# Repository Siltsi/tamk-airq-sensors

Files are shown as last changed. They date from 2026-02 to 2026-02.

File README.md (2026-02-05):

# TAMK AIRQ SENSORS  

## TEAM25  

**Members**  
- Eino Lausmaa ([@eino](https://github.com/LausmaaEino))  
- Samu Ojala ([@samu](https://github.com/SamuOj))  
- Tomi Tienhaara ([@tomi](https://github.com/TomiTien))  
- Totti Sillanpää ([@totti](https://github.com/Siltsi))  

## About  

This repository contains a hardware project developed for the **TAMK Summer Training 2025**. The project goal is to design and manifacture a custom circuit board and enclosure for **PCB-based particle sensor systems**.  

All PCBs in this project were designed using **KiCad**.  

## Models  

### ttgo_airq  

The **ttgo_airq** model is based on the LILYGO [T-Display](https://lilygo.cc/products/t-display). This model is currently in a **usable and tested state**.  

**Features:**  
- ESP32 with integrated display  
- Custom-designed PCB  
- 2 enclosure options  

**Enclosures:**  
- **Medium enclosure**  
  - Supports Sensirion [SEN5x](https://sensirion.com/products/catalog/SEK-SEN5x)  
  - Supports Sensirion [SCD41](https://sensirion.com/products/catalog/SEK-SCD41)  
- **Small enclosure**  
  - Supports Sensirion [SCD41](https://sensirion.com/products/catalog/SEK-SCD41) only  

### nodemcu_airq  

The **nodemcu_airq** model is based on the Joy-IT [NodeMCU ESP32](https://joy-it.net/en/products/SBC-NodeMCU-ESP32).  
This model is **still a work in progress**.  

**Current status:**  
- PCB design is expected to be functional  
- System-level development is ongoing  

**Display options:**  
- Large display using the Velleman [VMP400](https://www.velleman.eu/products/view/3-5-320-x-480-touchscreen-for-raspberry-pi-vmp400/?id=438240)  
- Smaller display  
- No display  

**Enclosures:**  
- No enclosures have been designed yet for this model

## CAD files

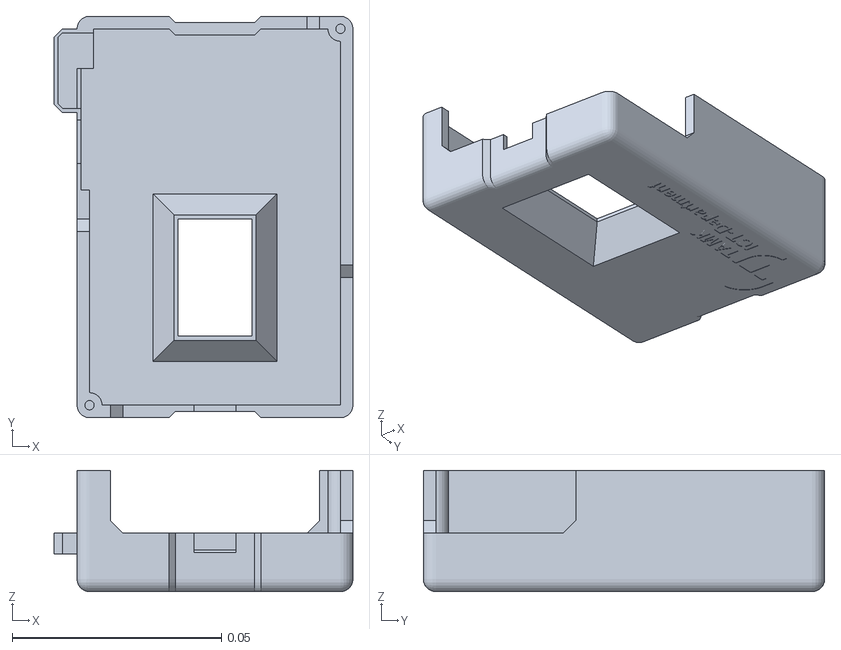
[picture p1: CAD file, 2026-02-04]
cases/ttgo_airq/small_case_top.stl
0.0715 x 0.096 x 0.029

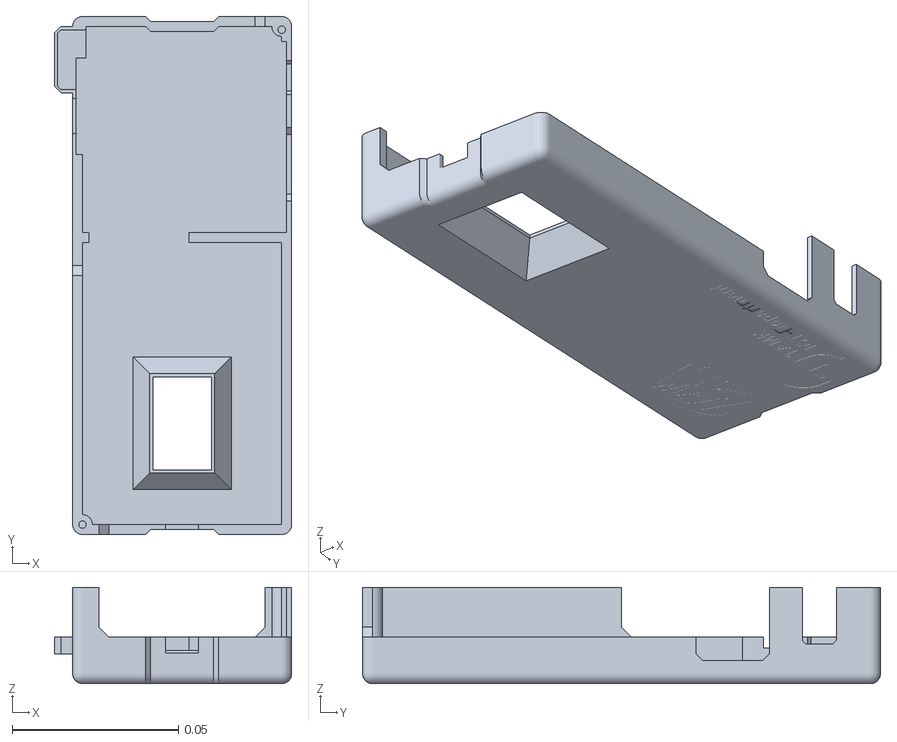
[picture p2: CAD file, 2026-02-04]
cases/ttgo_airq/medium_case_top_logo.stl
0.0715 x 0.156 x 0.029

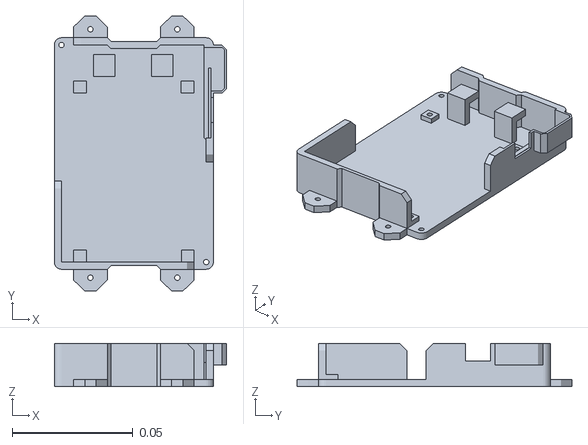
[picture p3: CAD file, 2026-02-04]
cases/ttgo_airq/small_case_bottom.stl
0.0715 x 0.114 x 0.018

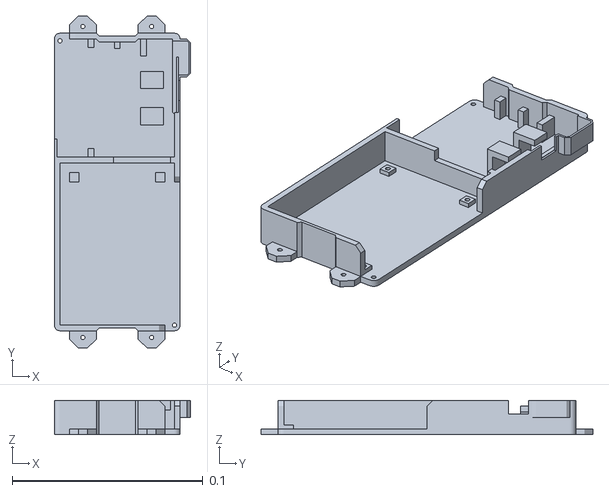
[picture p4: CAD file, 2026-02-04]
cases/ttgo_airq/medium_case_bottom.stl
0.0715 x 0.174 x 0.018

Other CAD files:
cases/ttgo_airq/medium_case_top.stl

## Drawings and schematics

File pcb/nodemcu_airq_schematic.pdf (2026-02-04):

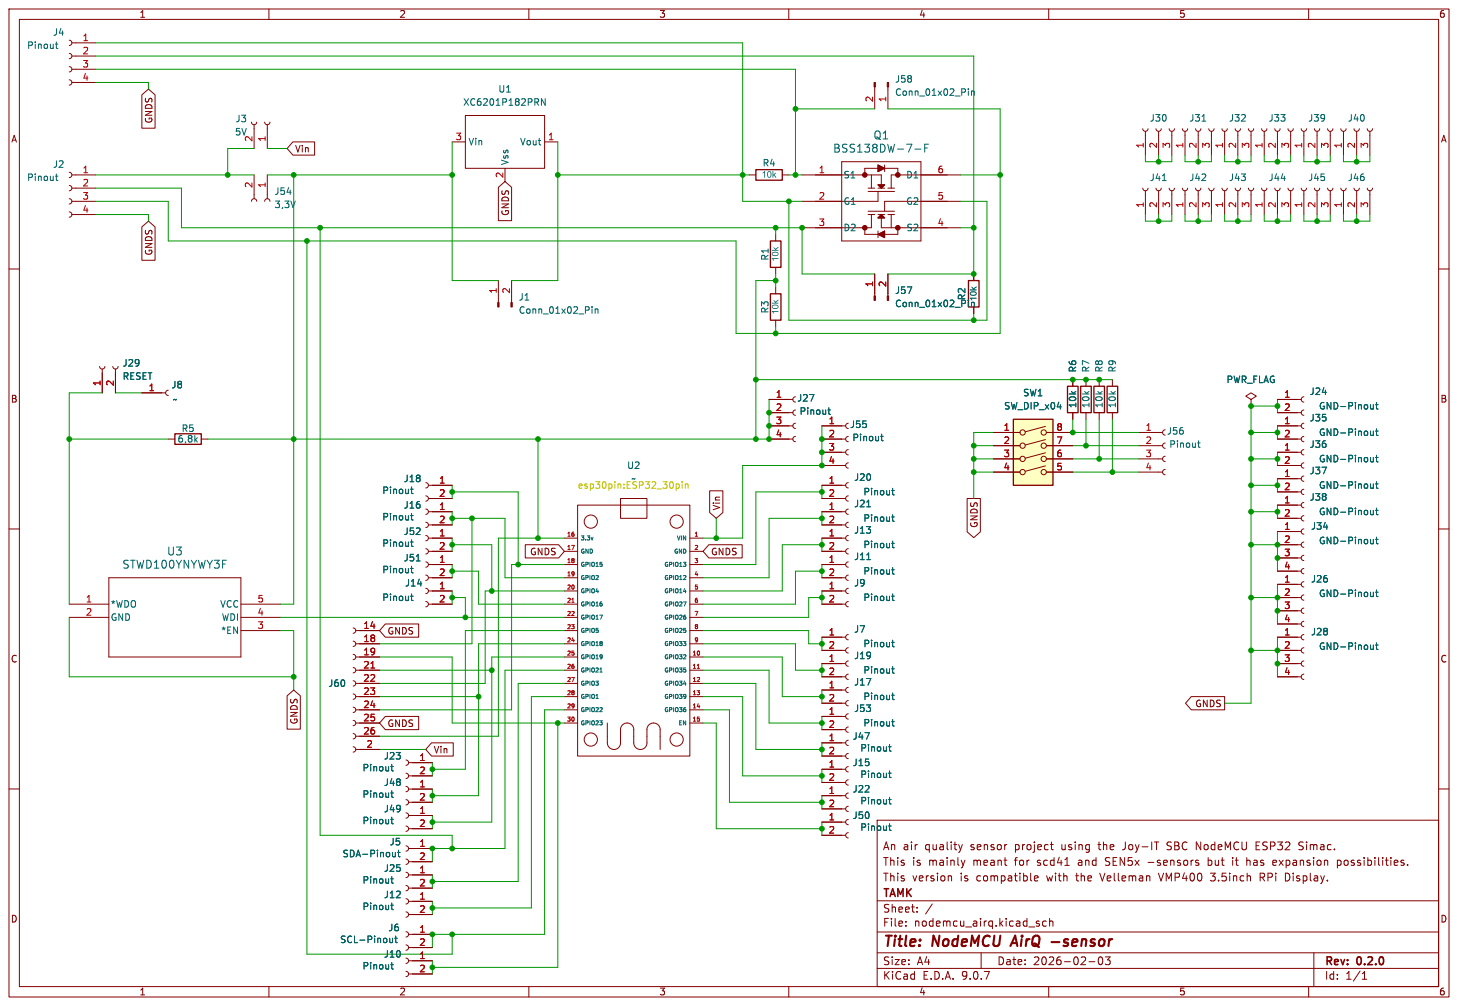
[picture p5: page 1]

Id: 1/1 Title: NodeMCU AirQ -sensor File: nodemcu_airq.kicad_sch Sheet: / TAMK

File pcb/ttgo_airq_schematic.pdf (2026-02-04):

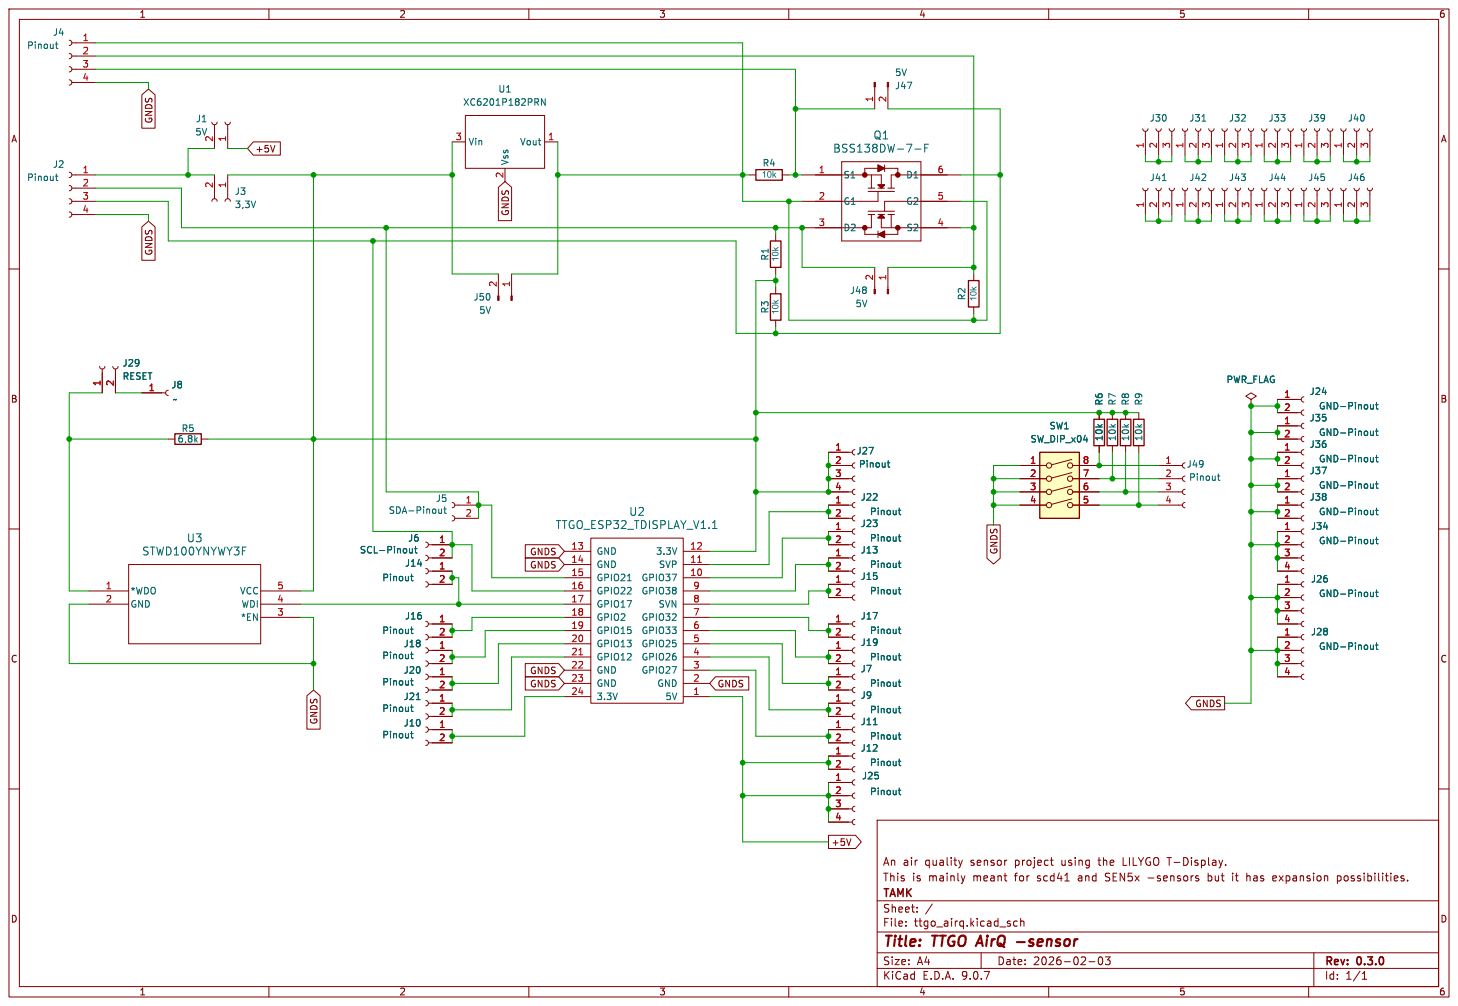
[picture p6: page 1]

Id: 1/1 Title: TTGO AirQ -sensor File: ttgo_airq.kicad_sch Sheet: / TAMK

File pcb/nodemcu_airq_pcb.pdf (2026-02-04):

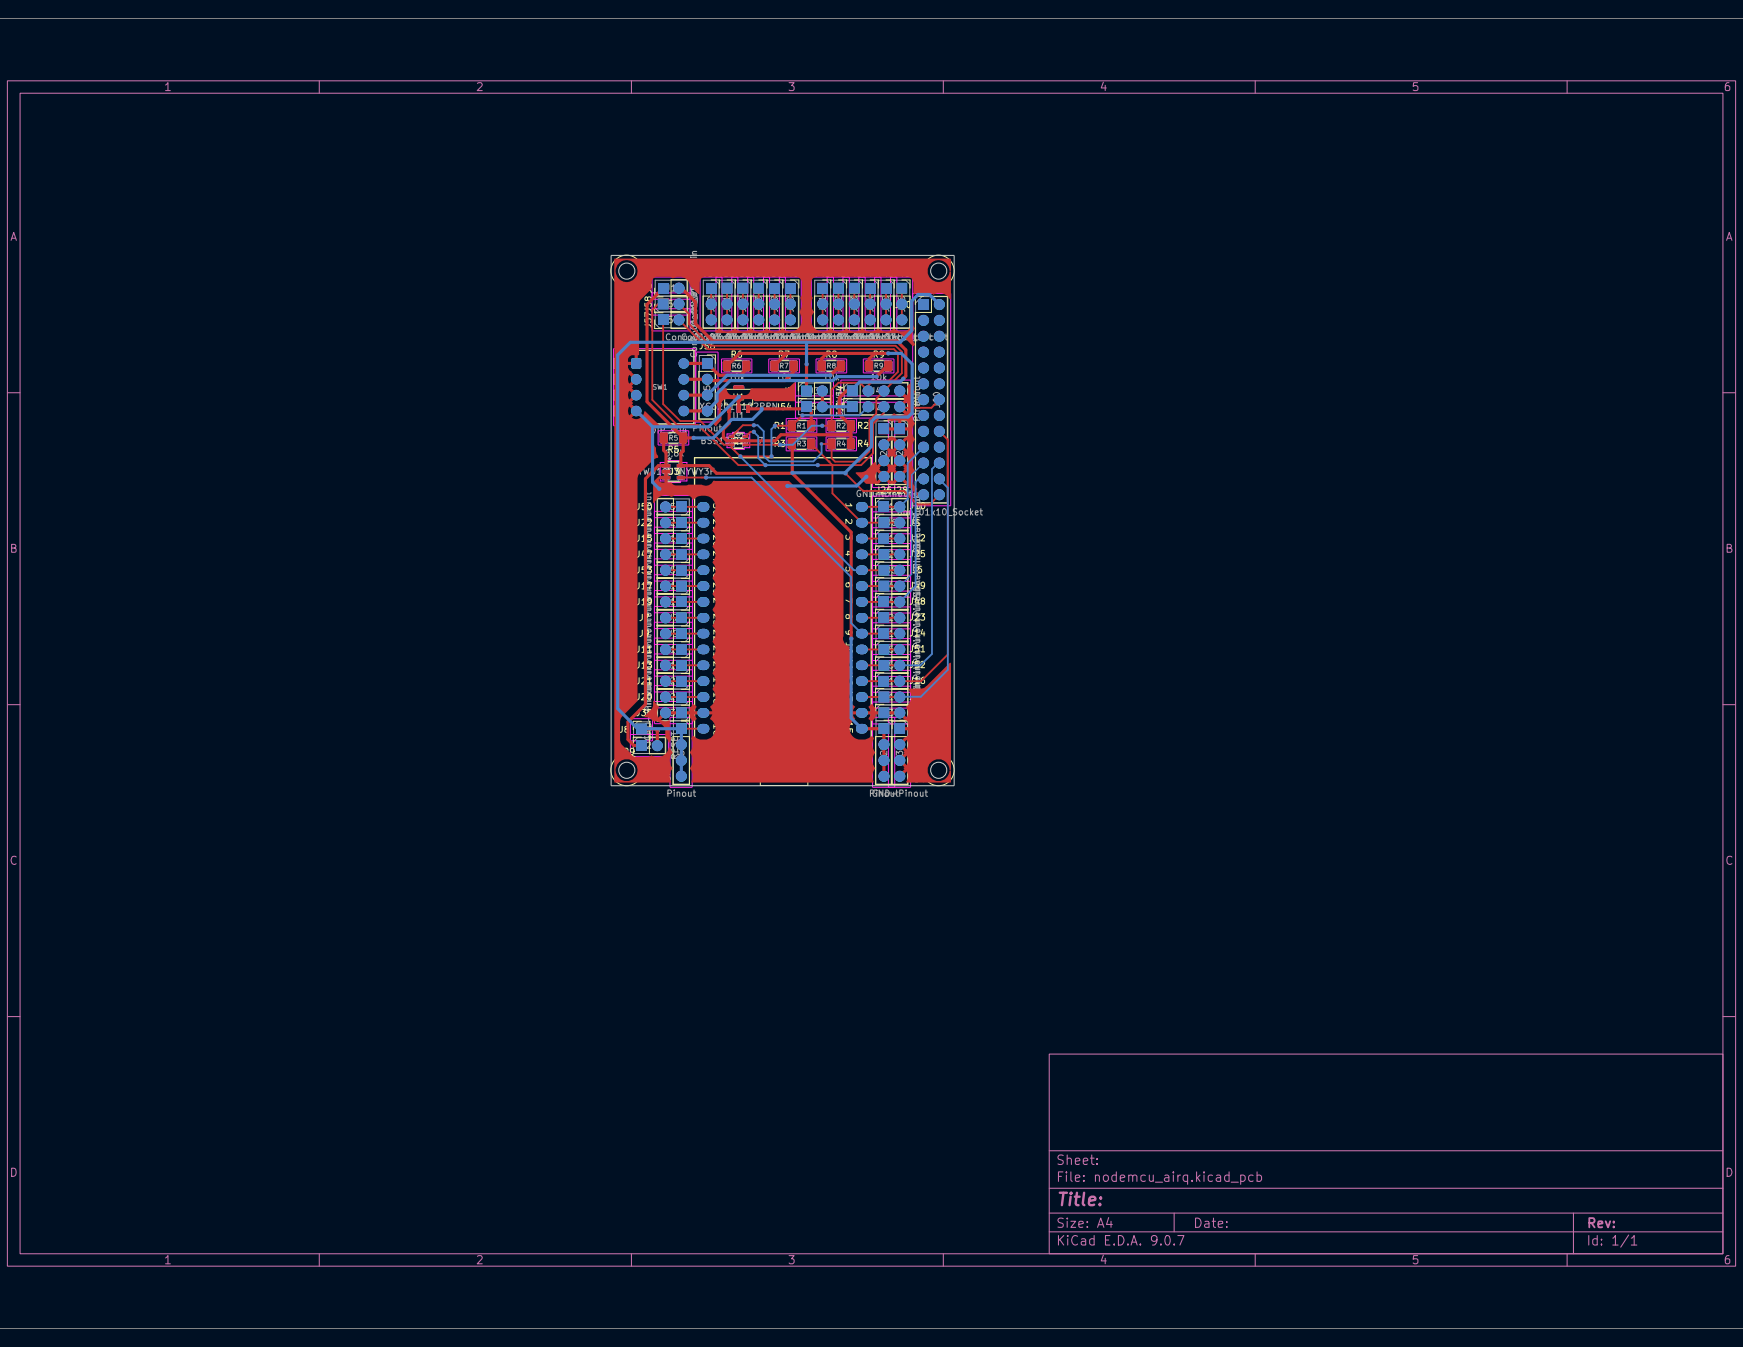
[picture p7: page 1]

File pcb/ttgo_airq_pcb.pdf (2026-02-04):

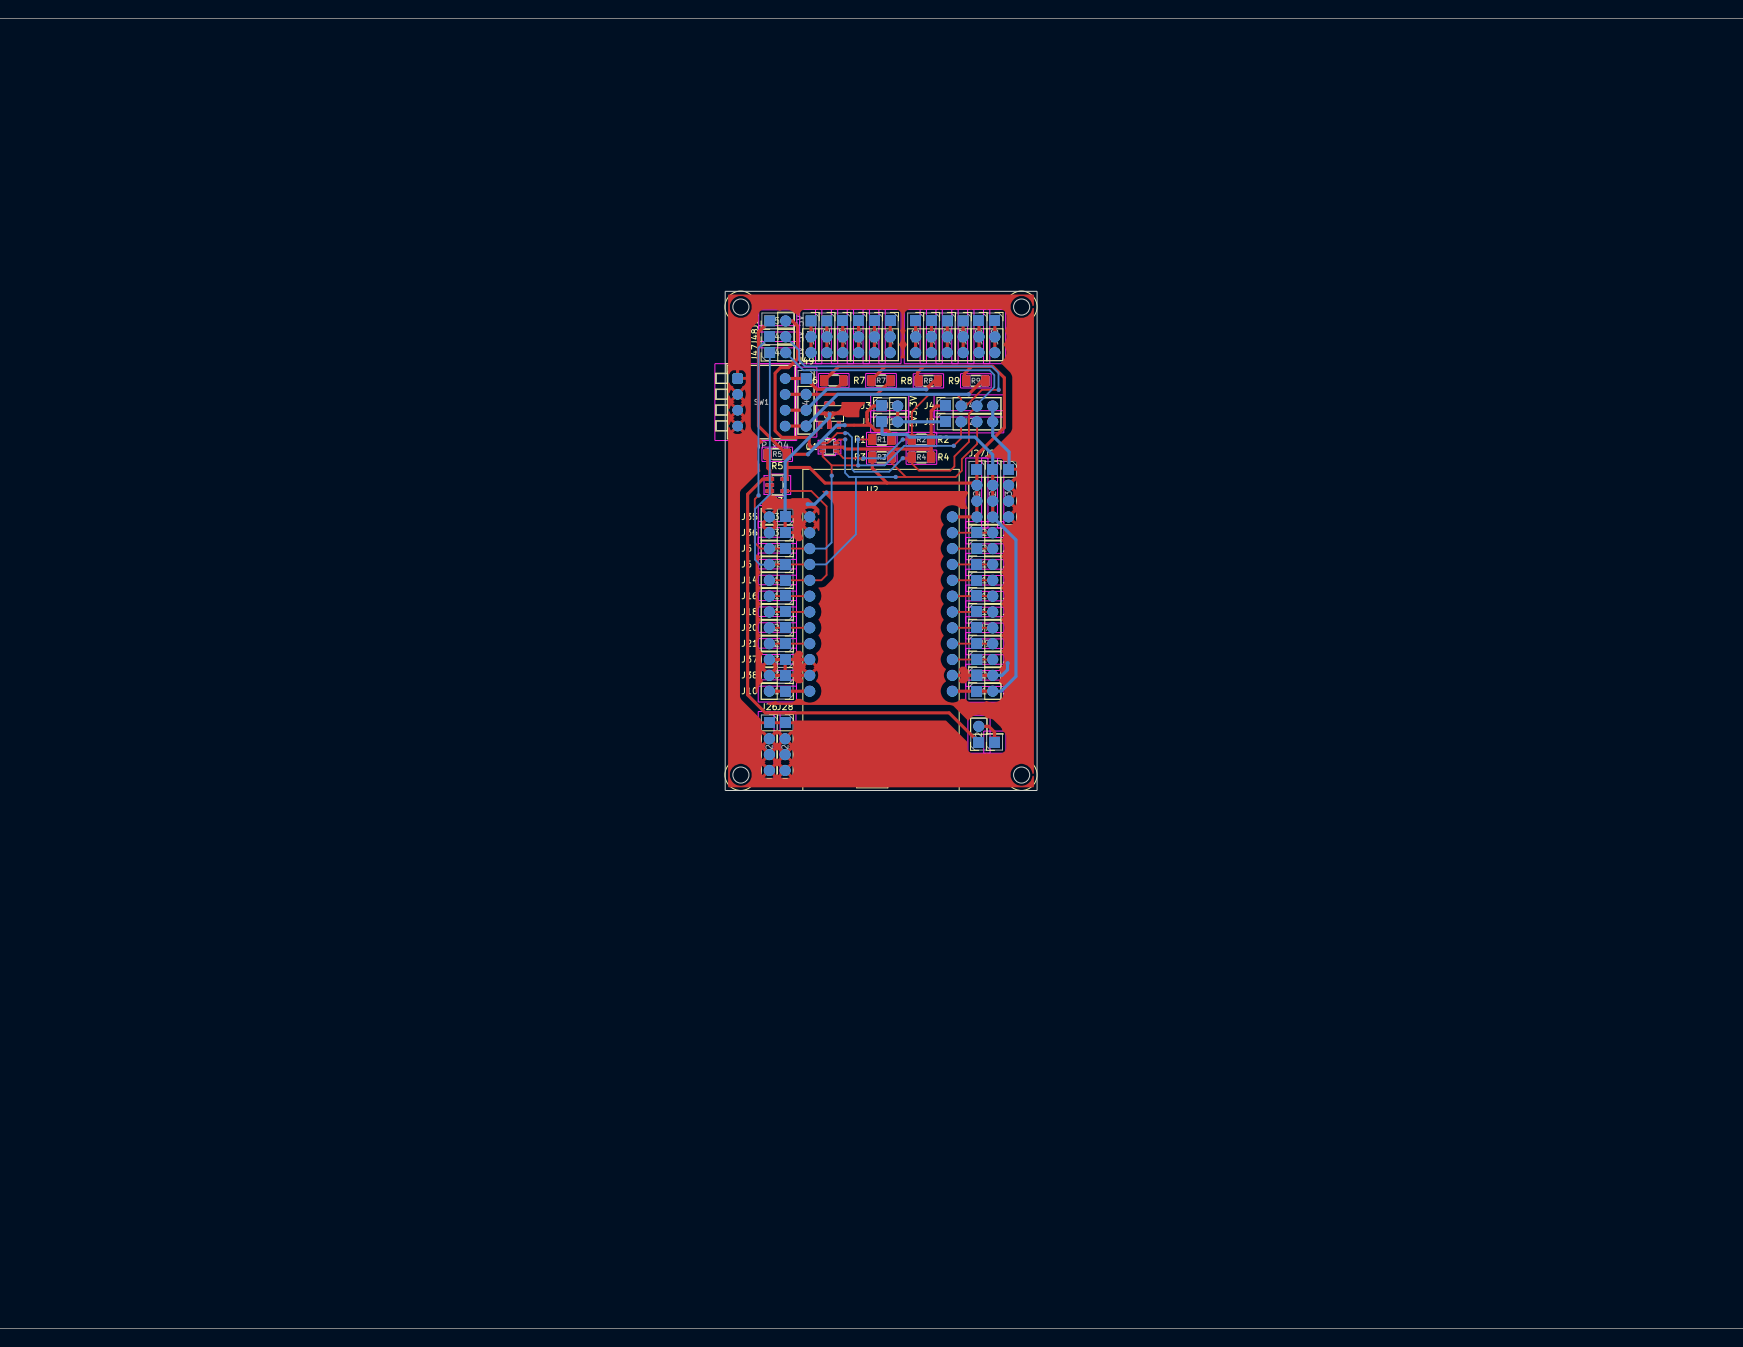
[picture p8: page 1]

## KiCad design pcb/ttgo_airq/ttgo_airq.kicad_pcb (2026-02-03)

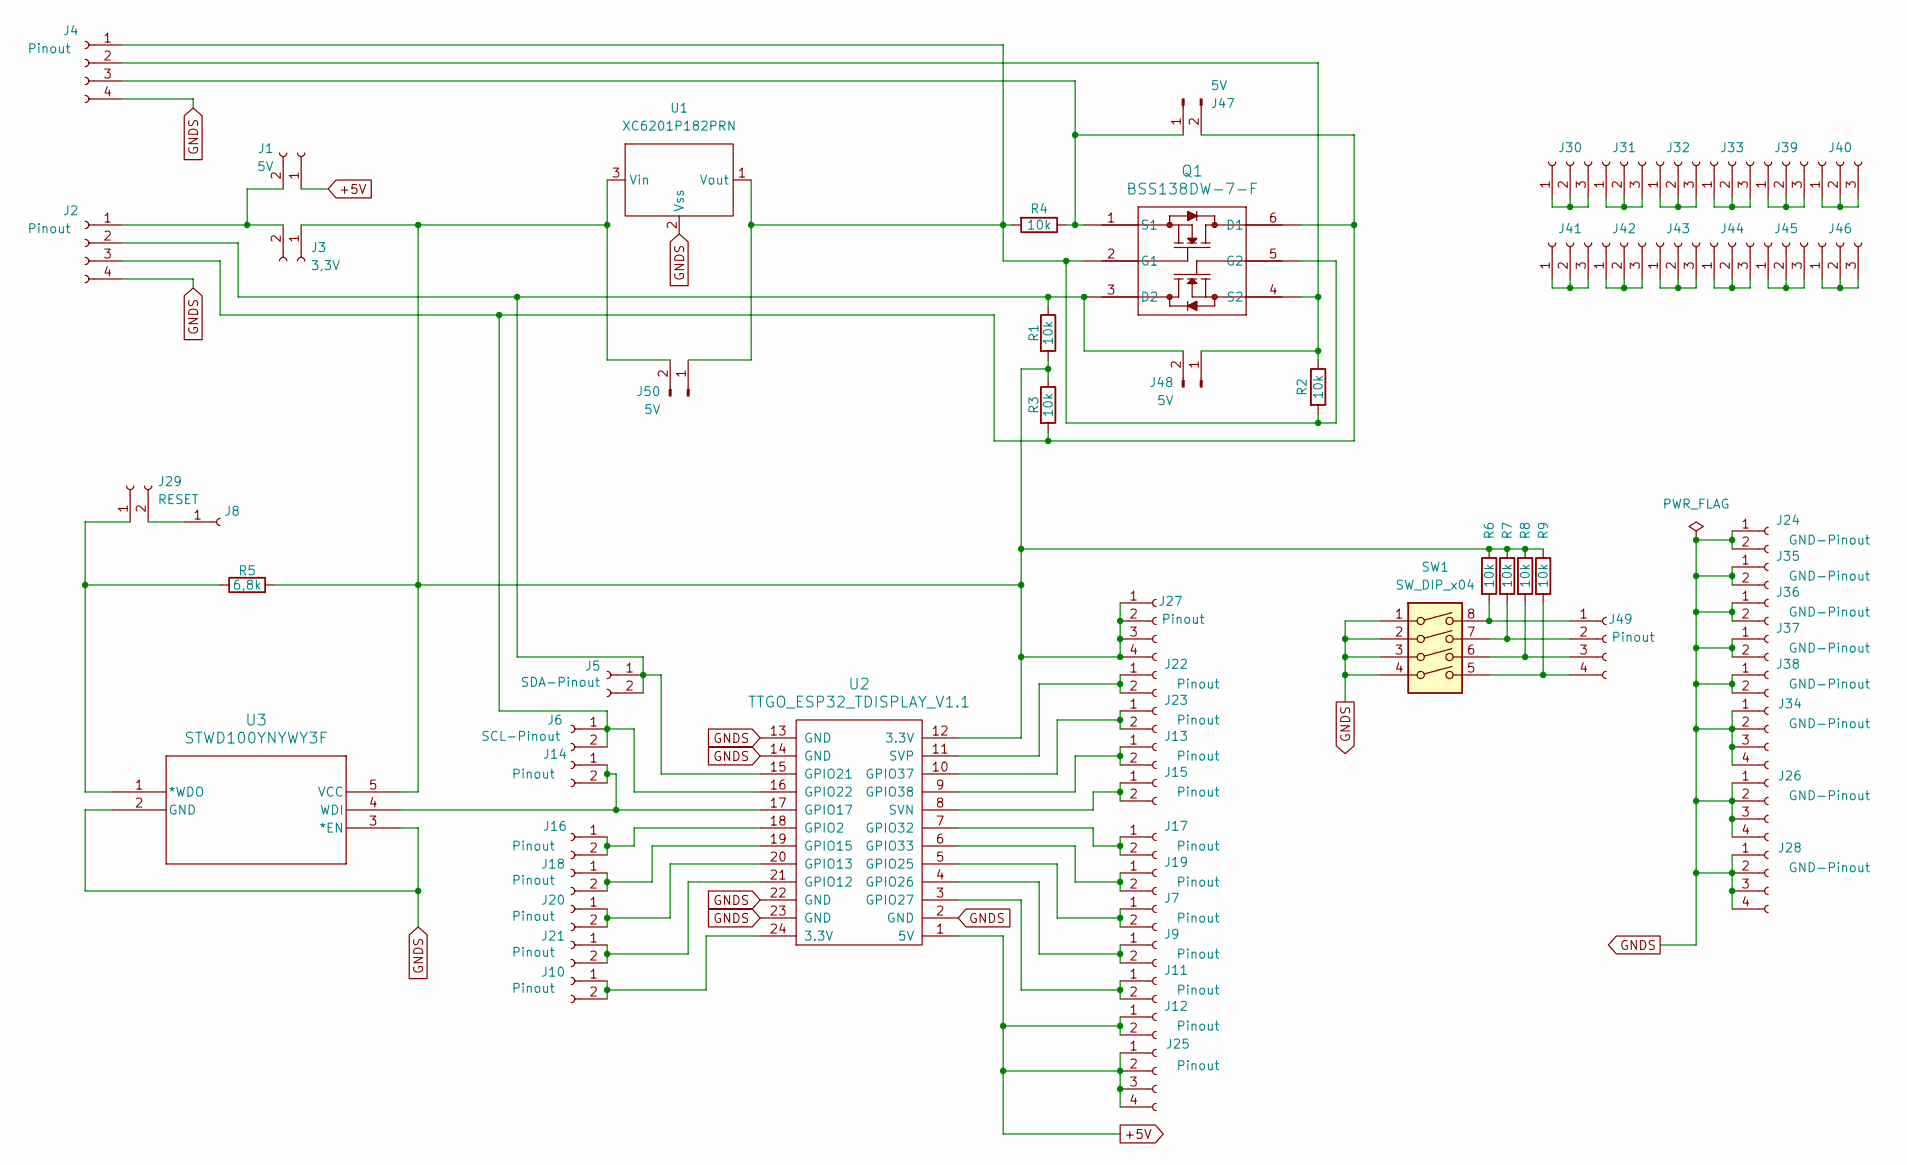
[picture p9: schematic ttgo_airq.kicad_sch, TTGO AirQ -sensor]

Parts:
J1: 5V; PinSocket_1x02_P2.54mm_Vertical
J2, J4, J25, J27, J49: Pinout; PinSocket_1x04_P2.54mm_Vertical
J3: 3,3V; PinSocket_1x02_P2.54mm_Vertical
J5: SDA-Pinout; PinSocket_1x02_P2.54mm_Vertical
J6: SCL-Pinout; PinSocket_1x02_P2.54mm_Vertical
J7, J9, J10, J11, J12, J13, J14, J15, J16, J17, J18, J19, J20, J21, J22, J23: Pinout; PinSocket_1x02_P2.54mm_Vertical
J8: PinSocket_1x01_P2.54mm_Vertical
J24, J35, J36, J37, J38: GND-Pinout; PinSocket_1x02_P2.54mm_Vertical
J26, J28, J34: GND-Pinout; PinSocket_1x04_P2.54mm_Vertical
J29: RESET; PinSocket_1x02_P2.54mm_Vertical
J30, J31, J32, J33, J39, J40, J41, J42, J43, J44, J45, J46: Conn_01x03_Socket; PinSocket_1x03_P2.54mm_Vertical
J47, J48, J50: 5V; PinHeader_1x02_P2.54mm_Vertical
Q1: BSS138DW-7-F; SOT363_DIO
R1, R2, R3, R4, R6, R7, R8, R9: 10k; R_1206_3216Metric_Pad1.30x1.75mm_HandSolder
R5: 6,8k; R_1206_3216Metric_Pad1.30x1.75mm_HandSolder
SW1: SW_DIP_x04; SW_DIP_SPSTx04_Piano_10.8x11.72mm_W7.62mm_P2.54mm
U1: XC6201P182PRN
U2: TTGO_ESP32_TDISPLAY_V1.1; TTGO-T-Display
U3: STWD100YNYWY3F; SOT23-5L_STM

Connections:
+5V: J1.1, J12.1, J12.2, J25.1, J25.2, J25.3, J25.4, U2.1 (5V)
GNDS: J2.4, J4.4, J24.1, J24.2, J26.1, J26.2, J26.3, J26.4, J28.1, J28.2, J28.3, J28.4, J34.1, J34.2, J34.3, J34.4, J35.1, J35.2, J36.1, J36.2, J37.1, J37.2, J38.1, J38.2, SW1.1, SW1.2, SW1.3, SW1.4, U1.2 (Vss), U2.2 (GND), U2.13 (GND), U2.14 (GND), U2.22 (GND), U2.23 (GND), U3.2 (GND), U3.3 (*EN)
unnamed: J1.2, J2.1, J3.2
unnamed: J2.2, J5.1, J5.2, J48.2, Q1.3 (D2), R1.1, U2.15 (GPIO21)
unnamed: J2.3, J6.1, J6.2, J47.2, Q1.6 (D1), R3.2, U2.16 (GPIO22)
unnamed: J4.1, J50.1, Q1.2 (G1), Q1.5 (G2), R2.2, R4.2, U1.1 (Vout)
unnamed: J4.2, J48.1, Q1.4 (S2), R2.1
unnamed: J4.3, J47.1, Q1.1 (S1), R4.1
unnamed: J7.1, J7.2, U2.5 (GPIO25)
unnamed: J9.1, J9.2, U2.4 (GPIO26)
unnamed: J10.1, J10.2, U2.24 (3.3V)
unnamed: J11.1, J11.2, U2.3 (GPIO27)
unnamed: J13.1, J13.2, U2.9 (GPIO38)
unnamed: J14.1, J14.2, U2.17 (GPIO17), U3.4 (WDI)
unnamed: J15.1, J15.2, U2.8 (SVN)
unnamed: J16.1, J16.2, U2.18 (GPIO2)
unnamed: J17.1, J17.2, U2.7 (GPIO32)
unnamed: J18.1, J18.2, U2.19 (GPIO15)
unnamed: J19.1, J19.2, U2.6 (GPIO33)
unnamed: J20.1, J20.2, U2.20 (GPIO13)
unnamed: J21.1, J21.2, U2.21 (GPIO12)
unnamed: J22.1, J22.2, U2.11 (SVP)
unnamed: J23.1, J23.2, U2.10 (GPIO37)
unnamed: J3.1, J27.1, J27.2, J27.3, J27.4, J50.2, R1.2, R3.1, R5.2, R6.1, R7.1, R8.1, R9.1, U1.3 (Vin), U2.12 (3.3V), U3.5 (VCC)
unnamed: J29.1, R5.1, U3.1 (*WDO)
unnamed: J8.1, J29.2
unnamed: J30.1, J30.2, J30.3
unnamed: J31.1, J31.2, J31.3
unnamed: J32.1, J32.2, J32.3
unnamed: J33.1, J33.2, J33.3
unnamed: J39.1, J39.2, J39.3
unnamed: J40.1, J40.2, J40.3
unnamed: J41.1, J41.2, J41.3
unnamed: J42.1, J42.2, J42.3
unnamed: J43.1, J43.2, J43.3
unnamed: J44.1, J44.2, J44.3
unnamed: J45.1, J45.2, J45.3
unnamed: J46.1, J46.2, J46.3
unnamed: J49.1, R6.2, SW1.8
unnamed: J49.2, R7.2, SW1.7
unnamed: J49.3, R8.2, SW1.6
unnamed: J49.4, R9.2, SW1.5

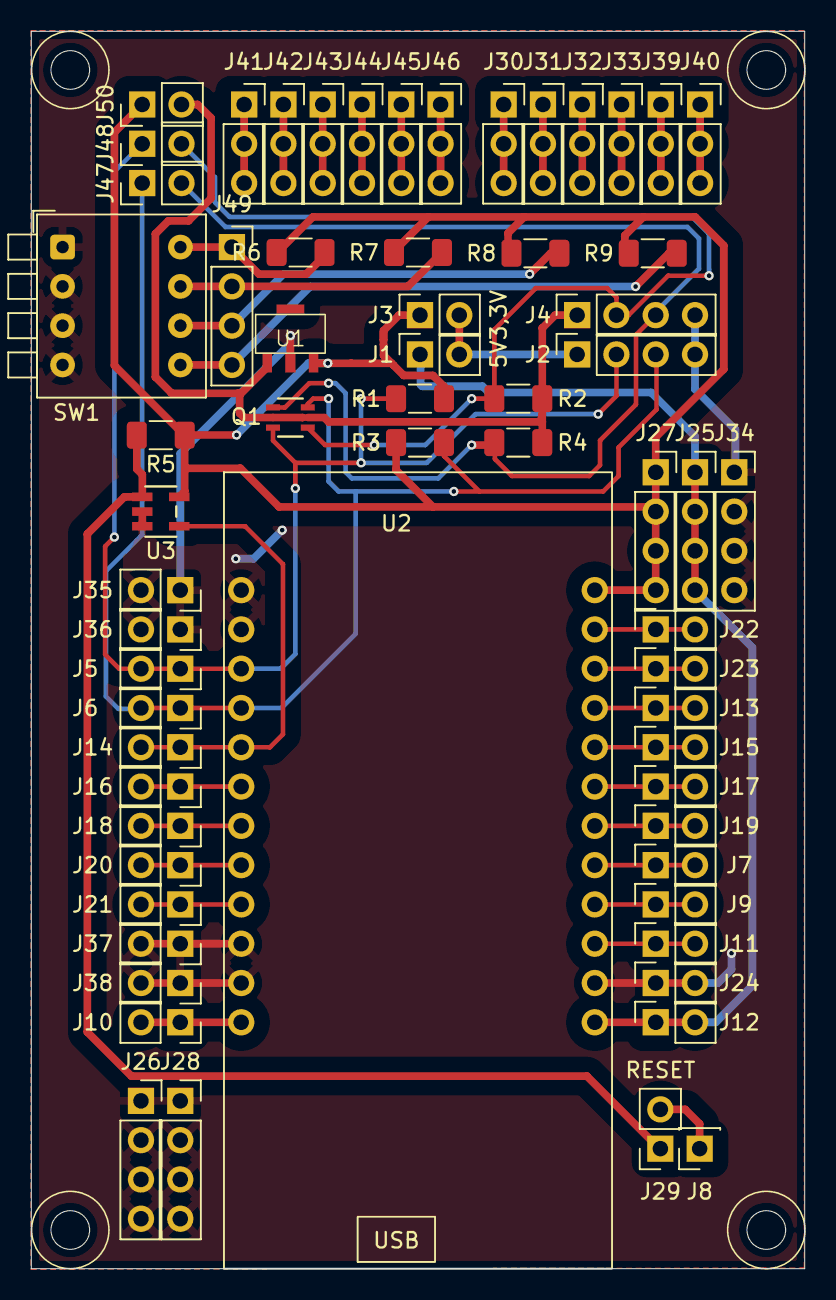
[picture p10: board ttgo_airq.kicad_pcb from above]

Board: 2 copper layers, 50.0 x 80.0 mm, 64 parts (0 on the bottom side), 42 nets.

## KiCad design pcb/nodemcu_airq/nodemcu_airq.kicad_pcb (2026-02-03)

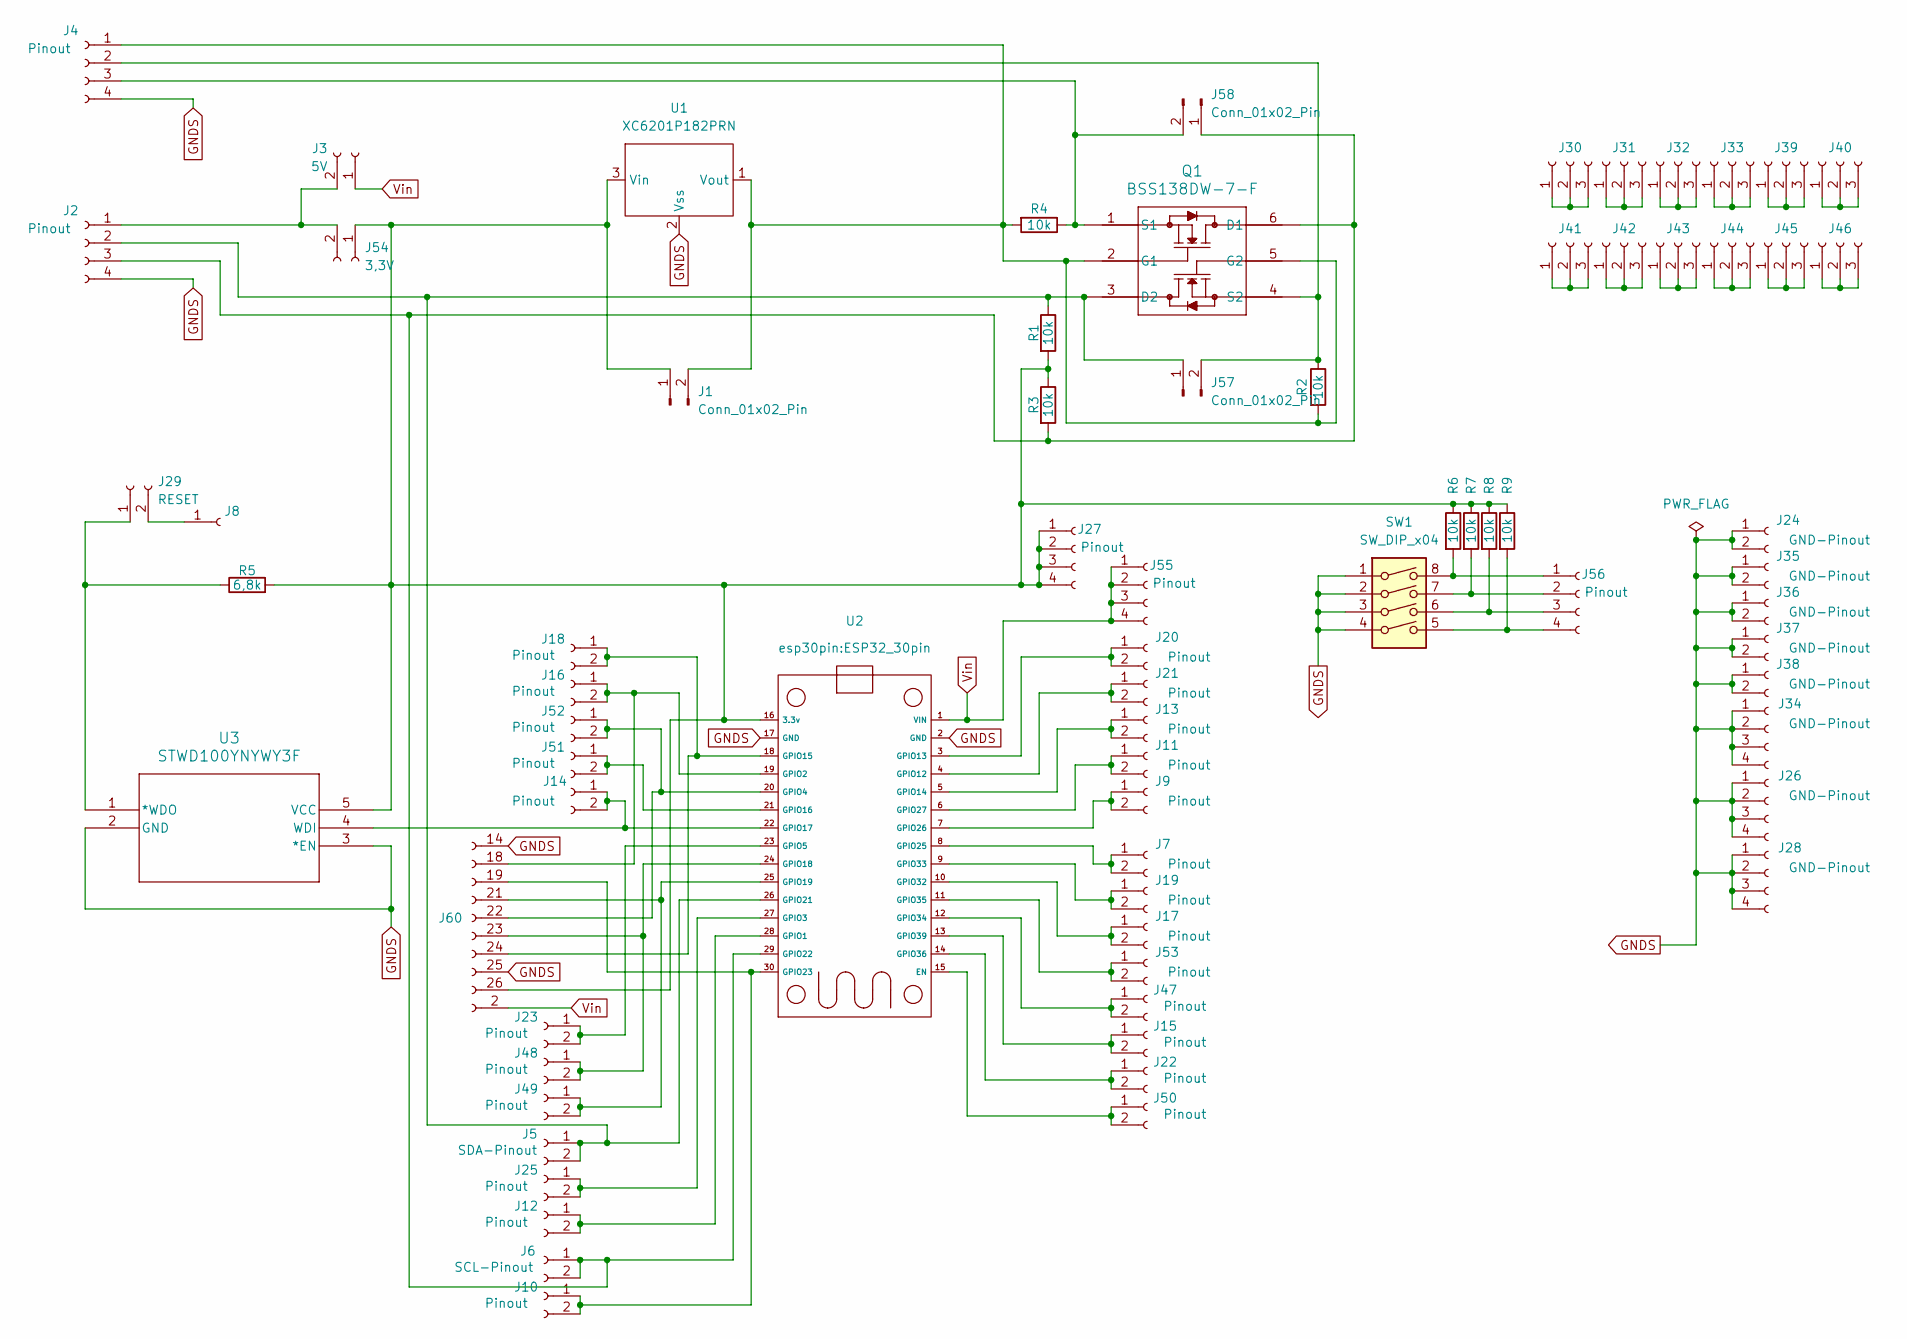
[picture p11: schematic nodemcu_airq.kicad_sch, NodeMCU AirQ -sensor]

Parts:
J1, J57, J58: Conn_01x02_Pin; PinHeader_1x02_P2.54mm_Vertical
J2, J4, J27, J55, J56: Pinout; PinSocket_1x04_P2.54mm_Vertical
J3: 5V; PinSocket_1x02_P2.54mm_Vertical
J5: SDA-Pinout; PinSocket_1x02_P2.54mm_Vertical
J6: SCL-Pinout; PinSocket_1x02_P2.54mm_Vertical
J7, J9, J10, J11, J12, J13, J14, J15, J16, J17, J18, J19, J20, J21, J22, J23, J25, J47, J48, J49, J50, J51, J52, J53: Pinout; PinSocket_1x02_P2.54mm_Vertical
J8: PinSocket_1x01_P2.54mm_Vertical
J24, J35, J36, J37, J38: GND-Pinout; PinSocket_1x02_P2.54mm_Vertical
J26, J28, J34: GND-Pinout; PinSocket_1x04_P2.54mm_Vertical
J29: RESET; PinSocket_1x02_P2.54mm_Vertical
J30, J31, J32, J33, J39, J40, J41, J42, J43, J44, J45, J46: Conn_01x03_Socket; PinSocket_1x03_P2.54mm_Vertical
J54: 3,3V; PinSocket_1x02_P2.54mm_Vertical
J60: Conn_01x10_Socket; PinSocket_2x13_P2.54mm_Vertical
Q1: BSS138DW-7-F; SOT363_DIO
R1, R2, R3, R4, R6, R7, R8, R9: 10k; R_1206_3216Metric_Pad1.30x1.75mm_HandSolder
R5: 6,8k; R_1206_3216Metric_Pad1.30x1.75mm_HandSolder
SW1: SW_DIP_x04; SW_DIP_SPSTx04_Piano_10.8x11.72mm_W7.62mm_P2.54mm
U1: XC6201P182PRN
U2: ESP32_30pin
U3: STWD100YNYWY3F; SOT23-5L_STM

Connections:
GNDS: J2.4, J4.4, J24.1, J24.2, J26.1, J26.2, J26.3, J26.4, J28.1, J28.2, J28.3, J28.4, J34.1, J34.2, J34.3, J34.4, J35.1, J35.2, J36.1, J36.2, J37.1, J37.2, J38.1, J38.2, J60.14 (Pin_1), J60.25 (Pin_8), SW1.1, SW1.2, SW1.3, SW1.4, U1.2 (Vss), U2.2 (GND), U2.17 (GND), U3.2 (GND), U3.3 (*EN)
unnamed: J1.1, J27.1, J27.2, J27.3, J27.4, J54.1, J60.26 (Pin_9), R1.2, R3.1, R5.2, R6.1, R7.1, R8.1, R9.1, U1.3 (Vin), U2.16 (3.3v), U3.5 (VCC)
unnamed: J1.2, J4.1, Q1.2 (G1), Q1.5 (G2), R2.2, R4.2, U1.1 (Vout)
unnamed: J2.1, J3.2, J54.2
unnamed: J2.2, J5.1, J5.2, J57.1, Q1.3 (D2), R1.1, U2.26 (GPIO21)
unnamed: J2.3, J6.1, J6.2, J58.1, Q1.6 (D1), R3.2, U2.29 (GPIO22)
unnamed: J4.2, J57.2, Q1.4 (S2), R2.1
unnamed: J4.3, J58.2, Q1.1 (S1), R4.1
unnamed: J7.1, J7.2, U2.8 (GPIO25)
unnamed: J9.1, J9.2, U2.7 (GPIO26)
unnamed: J10.1, J10.2, J60.19 (Pin_3), U2.30 (GPIO23)
unnamed: J11.1, J11.2, U2.6 (GPIO27)
unnamed: J12.1, J12.2, U2.28 (GPIO1)
unnamed: J13.1, J13.2, U2.5 (GPIO14)
unnamed: J14.1, J14.2, U2.22 (GPIO17), U3.4 (WDI)
unnamed: J15.1, J15.2, U2.13 (GPIO39)
unnamed: J16.1, J16.2, J60.18 (Pin_2), U2.19 (GPIO2)
unnamed: J17.1, J17.2, U2.10 (GPIO32)
unnamed: J18.1, J18.2, J60.24 (Pin_7), U2.18 (GPIO15)
unnamed: J19.1, J19.2, U2.9 (GPIO33)
unnamed: J20.1, J20.2, U2.3 (GPIO13)
unnamed: J21.1, J21.2, U2.4 (GPIO12)
unnamed: J22.1, J22.2, U2.14 (GPIO36)
unnamed: J23.1, J23.2, U2.23 (GPIO5)
unnamed: J25.1, J25.2, U2.27 (GPIO3)
unnamed: J29.1, R5.1, U3.1 (*WDO)
unnamed: J8.1, J29.2
unnamed: J30.1, J30.2, J30.3
unnamed: J31.1, J31.2, J31.3
unnamed: J32.1, J32.2, J32.3
unnamed: J33.1, J33.2, J33.3
unnamed: J39.1, J39.2, J39.3
unnamed: J40.1, J40.2, J40.3
unnamed: J41.1, J41.2, J41.3
unnamed: J42.1, J42.2, J42.3
unnamed: J43.1, J43.2, J43.3
unnamed: J44.1, J44.2, J44.3
unnamed: J45.1, J45.2, J45.3
unnamed: J46.1, J46.2, J46.3
unnamed: J47.1, J47.2, U2.12 (GPIO34)
unnamed: J48.1, J48.2, J60.23 (Pin_6), U2.24 (GPIO18)
unnamed: J49.1, J49.2, J60.21 (Pin_4), U2.25 (GPIO19)
unnamed: J50.1, J50.2, U2.15 (EN)
unnamed: J51.1, J51.2, U2.21 (GPIO16)
unnamed: J52.1, J52.2, J60.22 (Pin_5), U2.20 (GPIO4)
unnamed: J53.1, J53.2, U2.11 (GPIO35)
unnamed: J56.1, R6.2, SW1.8
unnamed: J56.2, R7.2, SW1.7
unnamed: J56.3, R8.2, SW1.6
unnamed: J56.4, R9.2, SW1.5
Vin: J3.1, J55.1, J55.2, J55.3, J55.4, J60.2 (Pin_10), U2.1 (VIN)

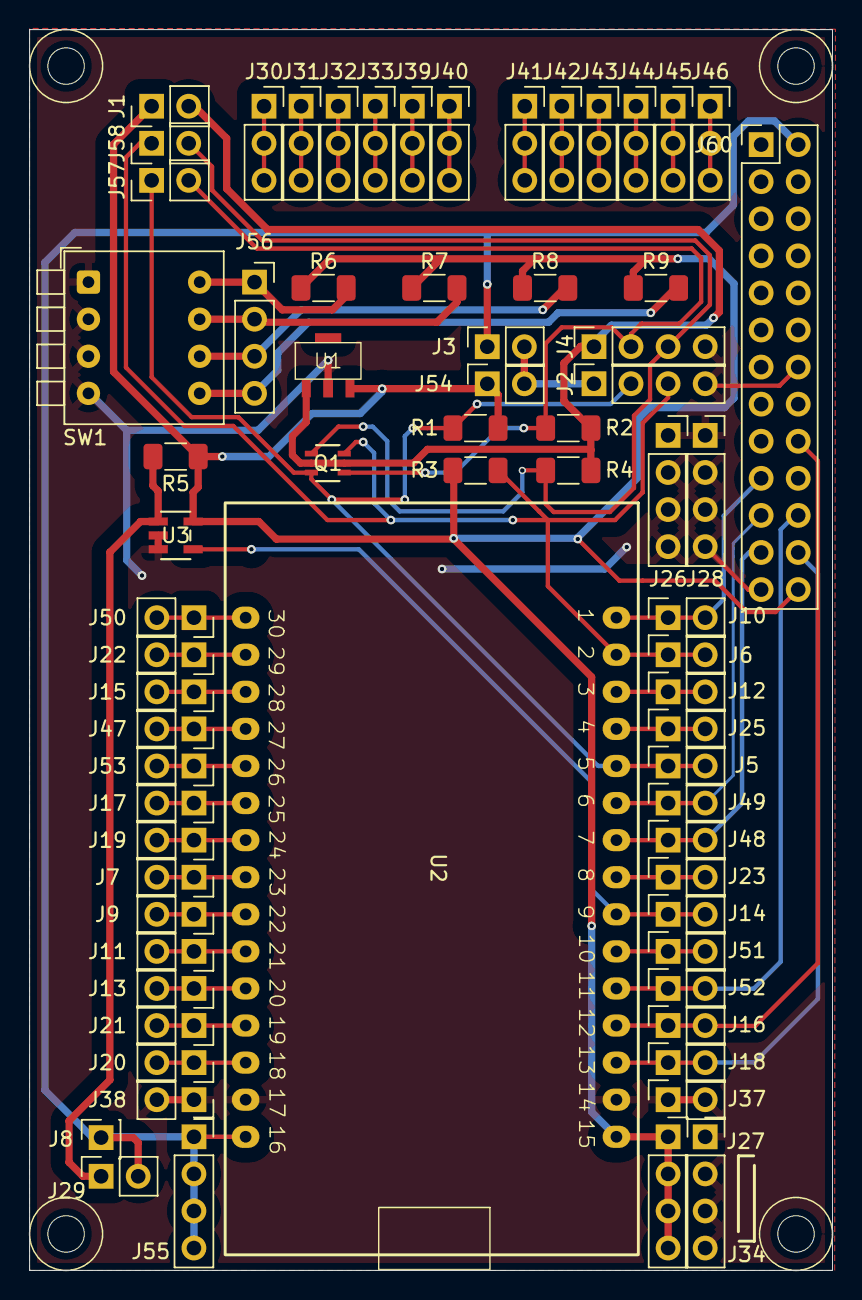
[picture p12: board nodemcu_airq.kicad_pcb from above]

Board: 2 copper layers, 55.0 x 85.0 mm, 70 parts (0 on the bottom side), 51 nets.

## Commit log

2026-02-03 Added TTGO and NodeMCU -projects
    [nodemcu_airq.kicad_pcb, nodemcu_airq.kicad_sch, ttgo_airq.kicad_pcb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]
2026-02-04 Added TTGO cases
    [medium_case_bottom.stl, medium_case_top.stl, medium_case_top_logo.stl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]
2026-02-04 Added Schematic and PCB pdfs
